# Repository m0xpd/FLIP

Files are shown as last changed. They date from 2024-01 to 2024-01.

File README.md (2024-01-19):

# FLIP

This repository describes a 'Bernoulli Gate', intended for switching applications in electronic music.

<p align='center'>
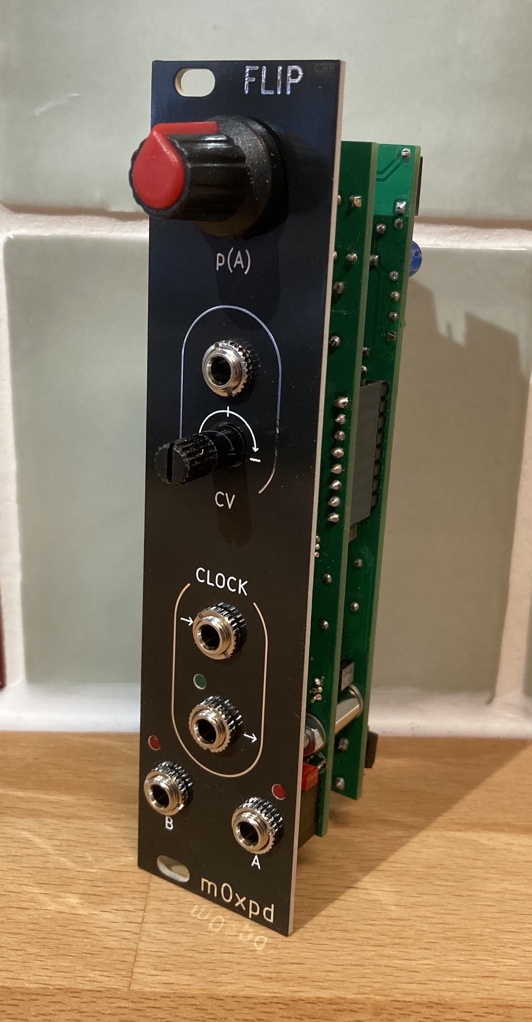
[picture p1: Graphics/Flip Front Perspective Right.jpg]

</p>
  
You can dive straight in to details of the [Eurorack module](https://github.com/m0xpd/Flip/blob/main/Eurorack/README.md), or a [stripboard layout for the circuit](https://github.com/m0xpd/FLIP/tree/main/Stripboard), or read more about the background and operation of this new design, below.

# Background

A Bernoulli Gate, named for Swiss mathematician and physicist [Daniel Bernoulli](https://en.wikipedia.org/wiki/Daniel_Bernoulli), takes a clock or gate input and routes it to one of two outputs, A & B, based on the 
value of an internally generated [Bernoulli Variable](https://web.stanford.edu/class/archive/cs/cs109/cs109.1178/lectureHandouts/070-bernoulli-binomial.pdf). When this (discrete, Boolean) random variable has value 1 the clock is routed to output A, and when the variable has value 0 the clock is routed to output B. The probability of the Bernoulli variable assuming value "1", p, is set by a front panel control (and/or by CV input). The probability of the variable assuming value "0" is (of course) 1-p. 

When the probability is set to p = 0.5, the process is equivalent to a "coin toss"; the input is routed to output A or B based on the outcome of a fair coin toss at each input onset. As p moves from the 0.5 value, the coin becomes increasingly "biased", with the outcome favouring one or other output. Larger values of p favors output A.

Bernoulli Gates have become familiar objects in modular synthesizers, the definitive example being Mutable Instruments' [Branches](https://pichenettes.github.io/mutable-instruments-documentation/modules/branches/) and various clones from other manufacturers. There is also a Bernoulli Gate within Mutable Instruments' [Marbles](https://pichenettes.github.io/mutable-instruments-documentation/modules/marbles/) module (and its clones), which is where it caught my interest. These implementations are achieved in software, running on microcontrollers.

# FLIP - a Hardware Bernoulli Gate

The Bernoulli Gate described in this repository is distinguished by being a completely **hardware realisation**. It generates the Bernoulli variable by a test of the instantaneous value of a linear ramp waveform. This ramp is running at a frequency several orders of magnitude above the clock frequencies typically used in synthesiser timing applications and is asynchronous to such input clocks/gates. Further, the ramp waveform is frequency-modulated by a second asynchronous signal, such that there is no possibility of 'phase' lock between an input clock and a subharmonic of the ramp waveform; the process is sufficiently random.

I should make it clear - I have absolutely nothing against the use of microcontrollers and DSP in modular synths, as I believe my work demonstrates. I designed FLIP for pleasure as a deliberate 'break' from playing with software-based systems in the recent development of my [STRACHEY](https://github.com/m0xpd/STRACHEY) sequencer. I based FLIP in hardware (rather than software) because I wanted the pleasure of something different. 

However, I should also confess to a feeling that we have become too ready to turn to soft solutions. There is something wasteful about having a little microcontroller (like Branches' ATMega88) sitting there doing something as simple as implementing (in that case two) Bernoulli Gates, even though it was *definitively the correct solution* for Mutable's commercial product. But I'm not designing for production - I'm enjoying myself, playing with ideas and materials I find to hand (often literally from the junk box). So - whilst I could easily have implemented my new Bernoulli Gate on an Atmel device or a PIC or similar, I think there remains something interesting and worthwhile in doing it 'old school'. 

I also recognise there are some members of the synth DIY community who actively do not like embedded/DSP. I repeat: **I'm NOT one of them**. But I'm pleased this project will be accessible to them.

Two versions of the hardware for FLIP are described in this repository. First, there is an implementation as a [Eurorack Module](https://github.com/m0xpd/Flip/blob/main/Eurorack/README.md), with full design details of the PCBs and front panel required for the 6HP module seen in the image at the head of this page. Second, I have included a [stripboard layout](https://github.com/m0xpd/Flip/blob/main/Stripboard/README.md) for the circuit for people who wish to build for a different format or who prefer to avoid the expense, delay, and minimum order quantities involved in making PCBs. The schematic for FLIP is presented as a single, system-level circuit in the [stripboard version](https://github.com/m0xpd/Flip/blob/main/Stripboard/README.md), whereas the [Eurorack version](https://github.com/m0xpd/Flip/blob/main/Eurorack/README.md) splits the system into two elements for implementation on two PCBs. Accordingly, those wishing to understand system operation might prefer to look at the schematic in the [stripboard folder](https://github.com/m0xpd/FLIP/tree/main/Stripboard) first. 

FLIP has two controls: the main 'probability' control and a control for the CV attenuverter. Advancing the probability control clockwise increases the probability that output A will be activated. When a positive CV is input, advancing the attenuverter control clockwise also increases the probability that A will 'fire' (the opposite sense applies when a negative CV is input). 

# Demo Video

A [short video](https://youtu.be/AdmhHrzYtKI), introduces FLIP and demonstrates its functions. The video is never going to win any oscars, not least as the camera is out of focus for the central 'demo' section. I don't know what changed between recording the music for the intro and 'closing credits' and the main, central demo portion. However, the message is clear, even if the image is not.    

# License

Material in this repository, including the circuit design and Eurorack implementation of FLIP, is published under a Creative Commons CC BY-SA 4.0 [License](https://github.com/m0xpd/Flip/blob/main/LICENSE.txt)

# Circuit Operation

Operation of the 'FLIP' Bernoulli Gate will now be described in some detail. Reference should be made to [this system-level schematic](https://github.com/m0xpd/Flip/blob/main/Stripboard/Graphics/m0xpd%20FLIP%20Bernoulli%20Gate.jpg) to which the component idents, circuit block names, and node names in the description below refer. [Note that these component idents differ from those used in the Eurorack version.]

FLIP derives a new value of a Bernoulli variable, p (as has been briefly introduced above) at the start of every clock input. This is done by comparing the instantaneous amplitude of a sawtooth wave to a threshold value. 

The sawtooth wave is generated by a 40106 oscillator (the block 'RAMP GENERATOR'), which is tuned (by adjustment of trimmer RV1, which should be set so there is approximately 1V on its wiper) to run at approximately 3.5kHz. The resulting sawtooth runs between voltages defined by the Schmitt trigger points of the 40106's inputs but the sawtooth is shifted to 0V mean by the high pass filter network C1,R3. Comparing this 'Saw' voltage with the fixed threshold voltage, 'Thres' (the magnitude of which is set either by the front panel probability potentiometer RV3 and/or by CV input to J2) produces a new Bernoulli variable, P at the output of the 'THRESHOLD COMPARATOR'. If the threshold is close to the bottom of the sawtooth's voltage range, the probability is close to (logical) one. If the threshold is close to the top of the sawtooth's voltage range, the probability is close to (logical) zero. the threshold voltage has been designed so it can be set slightly above or below the sawtooth's range, locking the probability to 1 or 0 (*and thereby setting the 'A' output on or off, with no switching action*), if required.

The photo below shows the 'Saw' waveform (in Yellow), the threshold voltage, 'Thres', set to just above the bottom of the sawtooth's voltage range (in Magenta) and the resulting Bernoulli variable, 'P' (in Cyan). The FM modulation of the saw oscillator (see below) has been disabled to make the image clearer and the results were captured from the prototype [stripboard](https://github.com/m0xpd/Flip/blob/main/Stripboard/README.md) system.

<p align='center'>
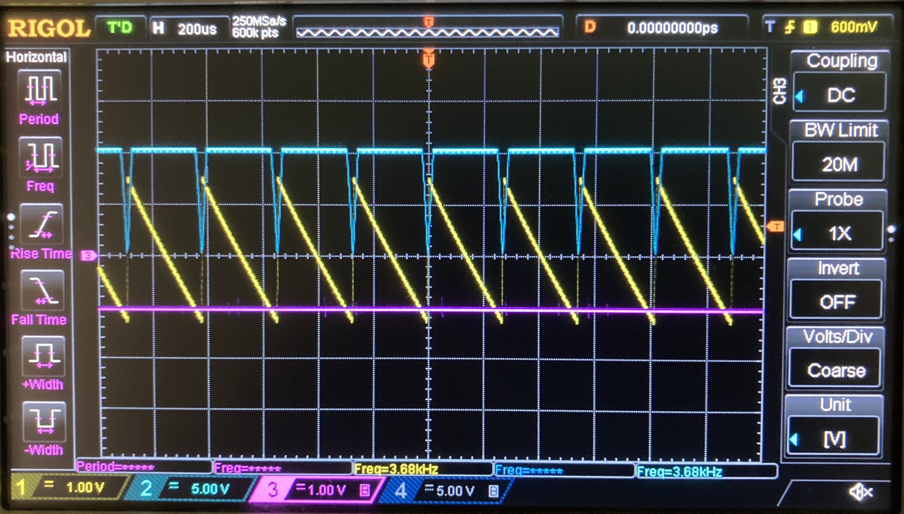
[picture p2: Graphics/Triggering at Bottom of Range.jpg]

</p>

It is seen that the Bernoulli variable is almost always "1", as expected.

In the practical circuit, frequency response and slew rate limitations in the op-amp used as the comparator constrain behaviour when the threshold is placed closer to the top of the sawtooth's range.

The photo below shows behaviour when the threshold, 'Thres' is at about 50% of the positive range of the sawtooth.

<p align='center'>
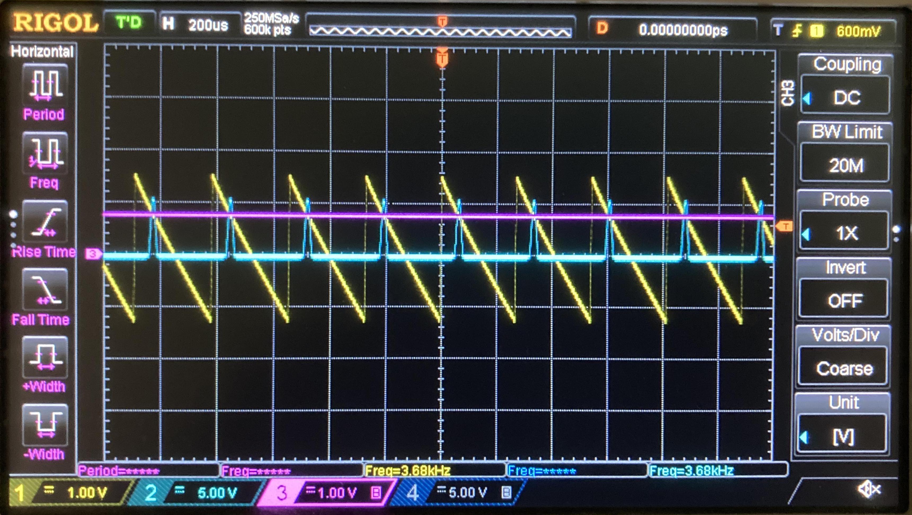
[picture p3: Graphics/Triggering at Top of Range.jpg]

</p>

It is seen that the Bernoulli variable is almost always "0"; this is the highest we can take the threshold voltage before it locks the gate "off". Taking the threshold value any higher in the practical circuit causes the comparator to fail to produce any 'non-zero' (in a logical sense) output. This is why the sawtooth wave - and the operation of FLIP - has been limited to 3.5kHz. 

The potential divider at the CV input, J2 (R13,R14) is loaded by the input resistance of the susbsequent attenuverter stage; this "loaded attenuator" produces around 6dB of attenuation in any configuration of the attenuverter. This allows a 5V CV signal to control the system, switching the gate from fully "on" to fully "off", whilst a higher CV input can achieve the same control at a lower attenuverter setting. Obviously, more subtle changes in configuration can be achieved with smaller control voltages, or with lower attenuverter settings.  

The external clock or gate signal is applied via J4 to FLIP's Schmitt trigger input circuit 'CLOCK IN' (with upward switchig threshold of 1.4V and downward threshold of 1.05V) to produce the gate signal, 'Input', which indicates an active input. The start of this input is detected by a typical passive differentiator / diode combination (C10,R30,D8), producing the signal 'dInput'.

The system is built around a trivial state machine which has two states, held on a SR flip-flop. I imlemented the flip-flop on 4001 (NOR) and 4081 (AND) gates, which were to hand (FLIP was designed around 'available materials') and provided sufficient logic resources for the remainder of the system. The transitions for the state machine were sufficient to define the Set and Reset signals:

The flip-flop is 'Set' when there is a leading edge of the clock AND the Bernoulli variable is 1 (Set = P.dInput).

The flip-flop is 'Reset' when 'Input' is false (Reset = _Input).

This system was found to work perfectly well in practical musical application, but offended me, as I understood there was possibility for a 'lock' between  a harmonic of the clock and the sawtooth wave, making the process less than random. I had anticipated this in design and arranged for the sawtooth oscillator to be voltage controlled. A second stage of the 40106 ('FM Osc') is used to implement an oscillator from which a triangular wave (at around 800Hz) is generated. This triangular voltage is used to frequency modulate the sawtooth, effectively removing the possibility of any 'lock' between the sawtooth and a periodic input signal. 

The photo below shows triggering with FM enabled:

<p align='center'>
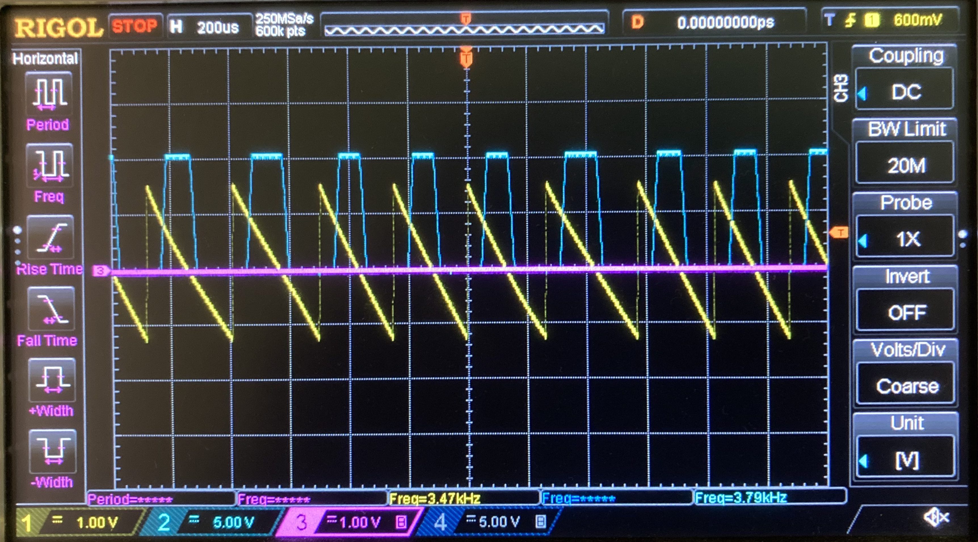
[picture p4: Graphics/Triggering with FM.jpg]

</p>

In this case, the threshold has been set to approximately 0V and the Bernoulli variable is returning a true value approximately 35% of the time (but not achieving the 50% score of a "fair" system, as the 0V threshold is above the middle of the range determined by the two limiting cases shown in the previous two oscilloscope screen shots). Variation in the period of the sawtooth (and the resulting outputs from the comparator) caused by the frequency modulation is clearly visible.

FLIP's three outputs use a simple 'emitter follower' buffer scheme taught by Ken Stone. The 'A' output follows directly the 'Q' output of the flip-flop. The 'B' output must be derived from additional logic to AND the complemented flip-flop state _Q with the input clock/gate signal. Finally, an output is provided which mirrors the input. This output is driven by a further inversion of _Input, rather than by adding load to the output of the CLOCK IN circuit, which could impact the edge detection circuit.

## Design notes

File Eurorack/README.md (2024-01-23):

# The 'FLIP' Bernoulli Gate for Eurorack

The Eurorack version of FLIP is implemented as a 'sandwich' construction of two printed circuit boards:

<p align='center'>
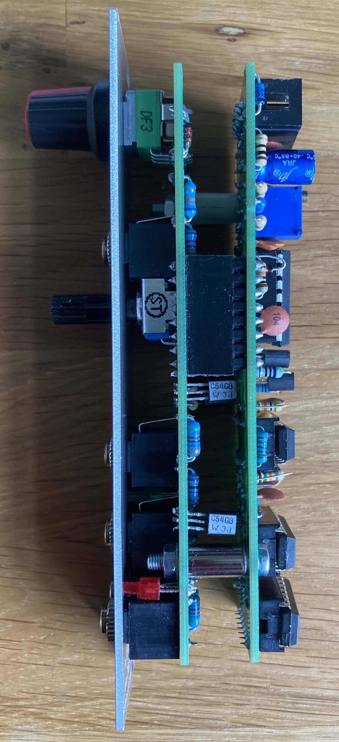
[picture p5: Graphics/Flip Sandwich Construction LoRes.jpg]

</p>

The [main board](https://github.com/m0xpd/FLIP/blob/main/Eurorack/Main%20Board/README.md) contains the majority of the active electronics, realised in 4000 series CMOS logic and a quad op-amp.

The [control board](https://github.com/m0xpd/FLIP/blob/main/Eurorack/Control%20Board/README.md) accommodates all the [front panel](https://github.com/m0xpd/FLIP/blob/main/Eurorack/Front%20Panel/README.md) components and the output buffer stages. 

The component board is mounted to the front panel by the probability control potentiometer, RV2, and five PJ398SM ('Thonkiconn') 3.5mm jack sockets.

The two PCBs are joined electrically by two 1*8 way 0.1 inch headers, with further mechanical security provided by a pair of 3mm bolts and spacers.

**Note:** the 12V line runs close to the upper spacer on the main board (on the bottom side of the PCB). If you use a metal spacer you would be well advised to insert an insulating washer at this point. I didn't have an insulating washer available on my first assembly, so I made an insulating spacer. This has now been replaced, as I got some M3 Nylon washers. Perhaps I'll move the 12V track if there's ever a revision of the PCB. 

Full design details of the [main board](https://github.com/m0xpd/FLIP/blob/main/Eurorack/Main%20Board/README.md), [control board](https://github.com/m0xpd/FLIP/blob/main/Eurorack/Control%20Board/README.md), and [front panel](https://github.com/m0xpd/FLIP/blob/main/Eurorack/Front%20Panel/README.md) are presented as KiCad projects. The folders also include schematics and BoMs, where relevant.

Populated boards from my first build are seen below.

First, there is an exploded view of the "outside" of the sandwich; the component side of the main board (left) and the bottom side of the control board (right), which houses the "user interface" components which protrude through the front panel:

<p align='center'>
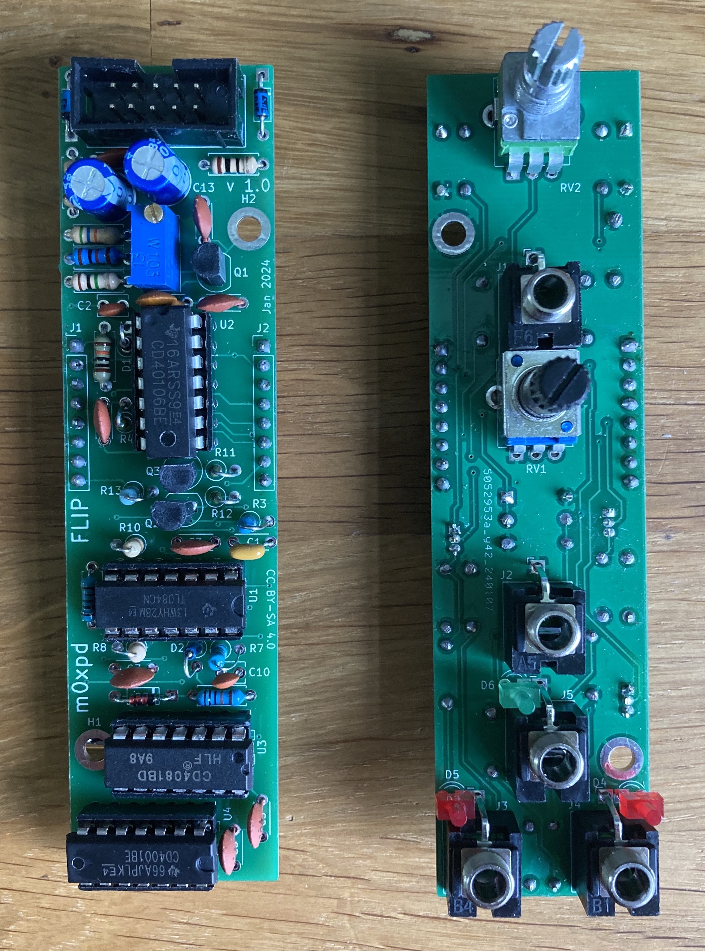
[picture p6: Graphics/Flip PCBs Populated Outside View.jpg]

</p>

Finally, an exploded view of the "inside" of the sandwich, showing the headers which join the boards, the bottom of the main board (left), and the component side of the control board (right):

<p align='center'>
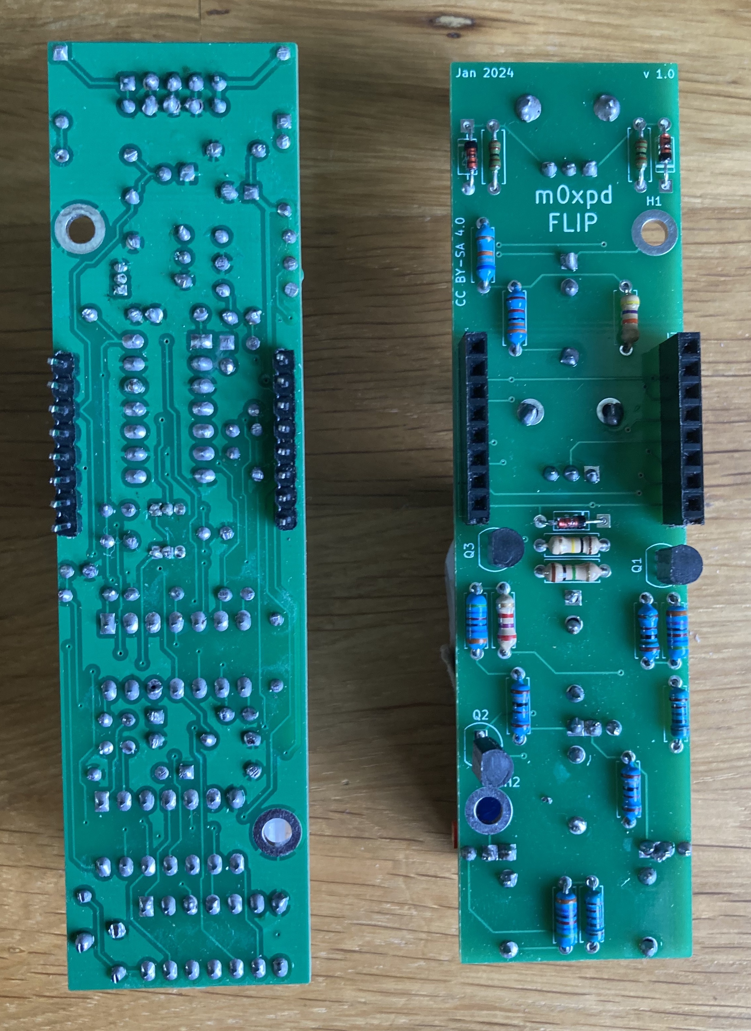
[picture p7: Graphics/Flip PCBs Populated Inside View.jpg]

</p>

(The two boards are exactly the same size but sit at slightly different distances from the camera in the images above, making them *appear* differently dimensioned.)

# Specifications

**Width:** 

FLIP is **6 HP wide**.

**Depth:**

FLIP extends **43 mm** behind the [front panel](https://github.com/m0xpd/FLIP/blob/main/Eurorack/Front%20Panel/README.md) when a conventional Eurorack power header **with strain relief** is inserted.

**Power Consumption:**

| Power Rail | Current |
|---|---|
| +12V | **5.5mA** (max) |
| -12V | **2.7mA** (max) |
| 5V | **0** |

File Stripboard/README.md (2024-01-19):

# A Stripboard Layout for the 'FLIP' Bernoulli Gate

During development I made a prototype on stripboard, based on a design made in [DIYLC](https://bancika.github.io/diy-layout-creator/) :

<p align='center'>
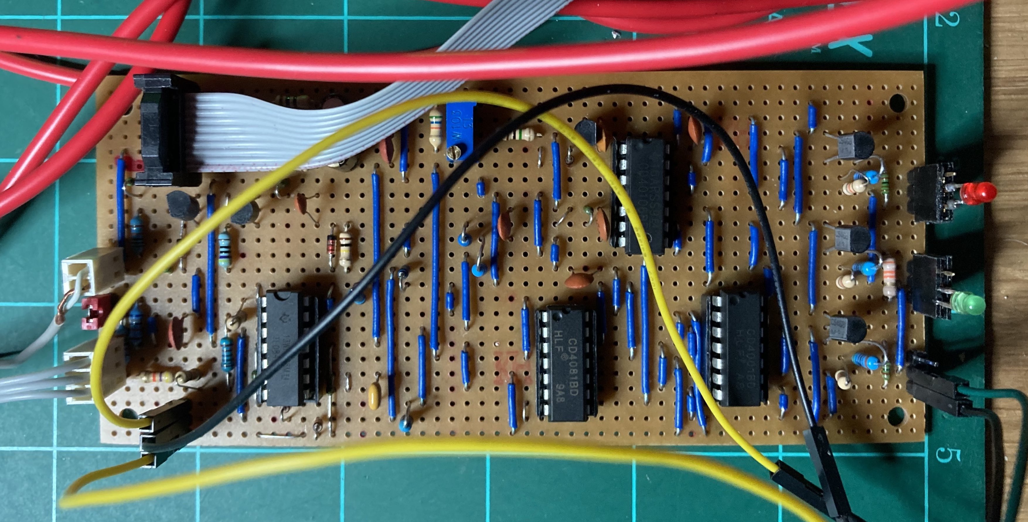
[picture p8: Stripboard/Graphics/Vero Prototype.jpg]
  
</p>

I have decided (for the first time) to publish a stripboard layout for this project as 
* it is small enough to make the stripboard layout manageable
* there is a considerable tradition within synth DIY for the use of stripboard - as demonstrated at [Eddy Bergman's site](https://www.eddybergman.com/)
* the test/development version was close enough to completion to make this task simple and, finally, 
* publishing a stripboard layout might make FLIP accessible to a few more potential users, who might otherwise be put off by the PCBs.

The stripboard layout will work well in "Kosmo" and MU applications etc (although the main board can easily be adapted for these formats too). There's more discussion of the implications of the stripboard layout's size [here](https://github.com/m0xpd/FLIP/blob/main/Stripboard/README.md#board-size-and-operation-on-different-power-rails)

# System Schematic

Before presenting the stripboard layout, we need to look at the schematic for the entire system (presented here as one sheet - unlike in the [Eurorack folder](https://github.com/m0xpd/FLIP/tree/main/Eurorack), where there are separate sheets for the two PCBs).

The schematic is linked below (click on the image to open the schematic at higher-resolution, which you can download):
<p align='center'>
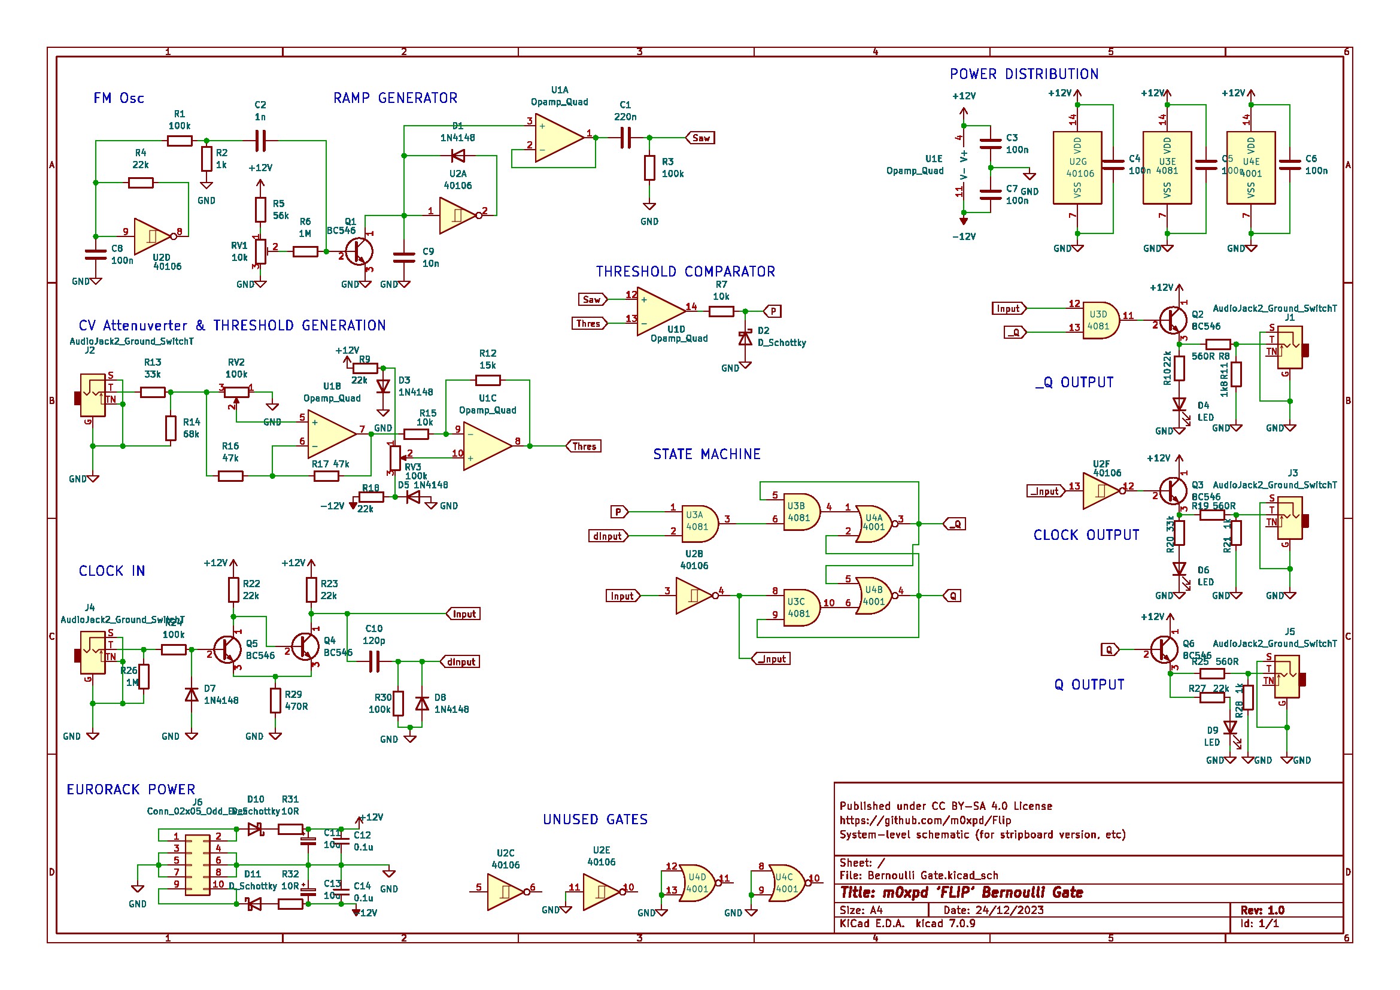
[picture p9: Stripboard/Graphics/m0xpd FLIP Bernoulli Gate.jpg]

</p>

There is a fairly detailed description of circuit operation, which references the schematic above, [here](https://github.com/m0xpd/Flip/tree/main#circuit-operation).

# Stripboard Layout

The prototype stripboard system seen pictured at the head of this page was made from a DIYLC design, which was found to have a few errors (this was my first time using the software). 

I corrected these errors on the prototype and on the layout, yielding the following design:

<p align='center'>
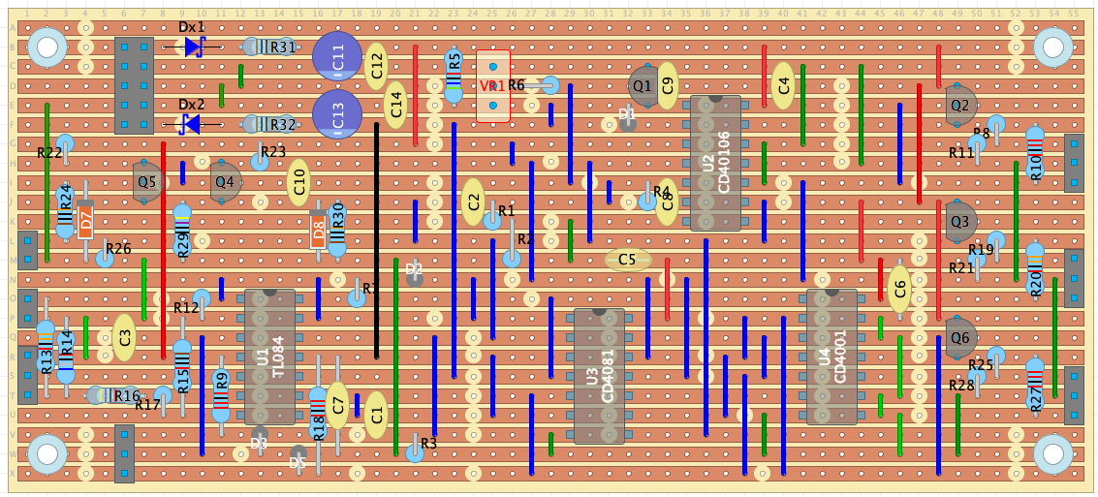
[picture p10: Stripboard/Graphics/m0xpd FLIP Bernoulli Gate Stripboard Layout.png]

</p>

In an attempt to make the layout clearer, +12V power links are shown in red, GROUND links are in green and -12V links are black. The remainder are blue.

The board is shown below (viewed from the **top/component side**) without components, to allow the cuts and links to be more clearly seen:

<p align='center'>
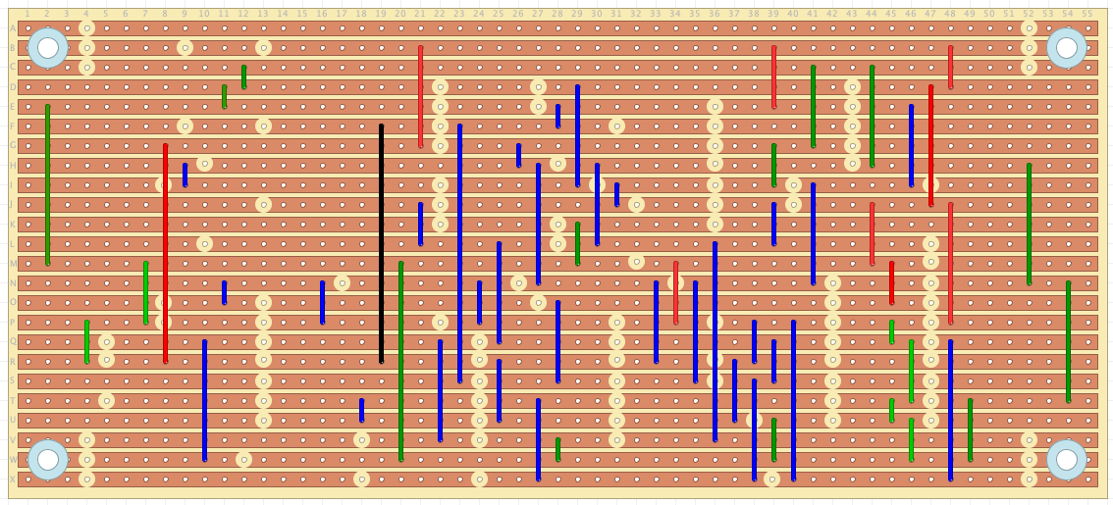
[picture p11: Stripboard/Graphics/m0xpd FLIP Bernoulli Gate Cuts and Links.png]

</p>

Finally, an image showing off-board connections is seen here:

<p align='center'>
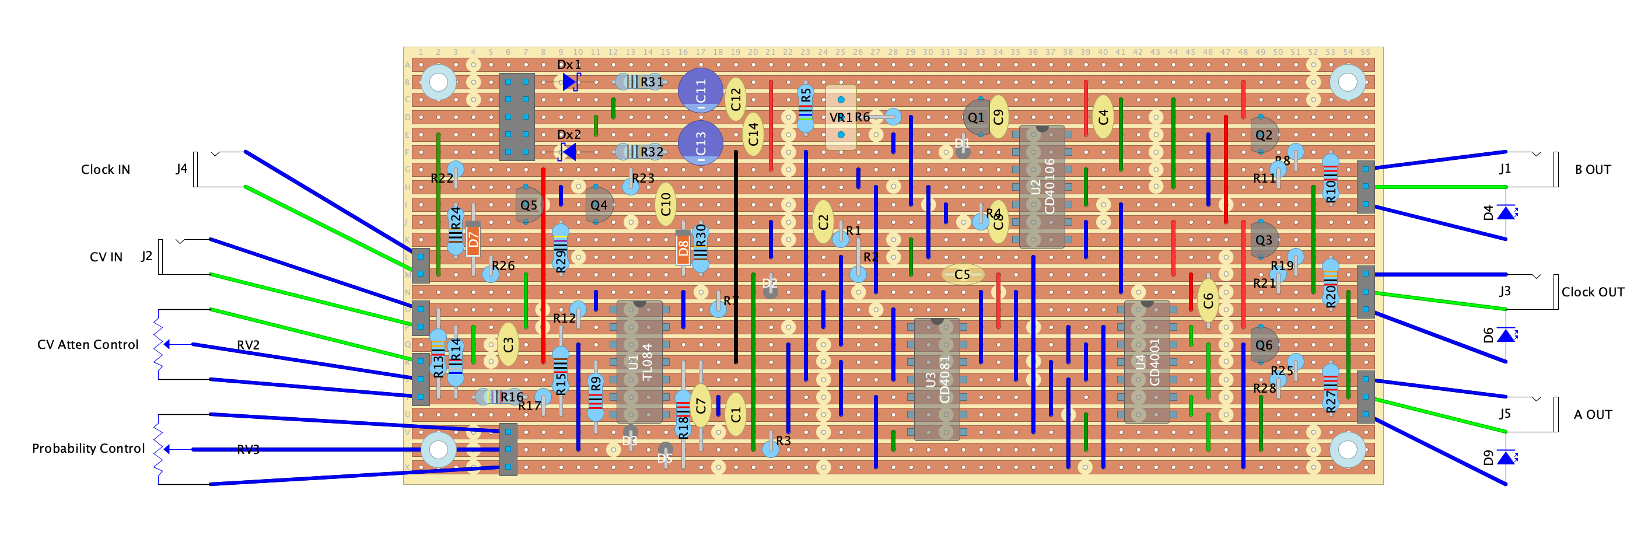
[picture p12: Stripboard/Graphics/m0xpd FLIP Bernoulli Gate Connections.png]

</p>

The entire DIYLC file is available for download [here](https://github.com/m0xpd/Flip/blob/main/Stripboard/Graphics/m0xpd%20FLIP%20Bernoulli%20Gate.diy). It must be opened in [DIYLC](https://bancika.github.io/diy-layout-creator/)

For those not familiar with github, the DIYLC file will open as a text file in a new window - you need to download the "Raw File", by clicking on the button at top right of the screen, as shown below:

<p align='center'>
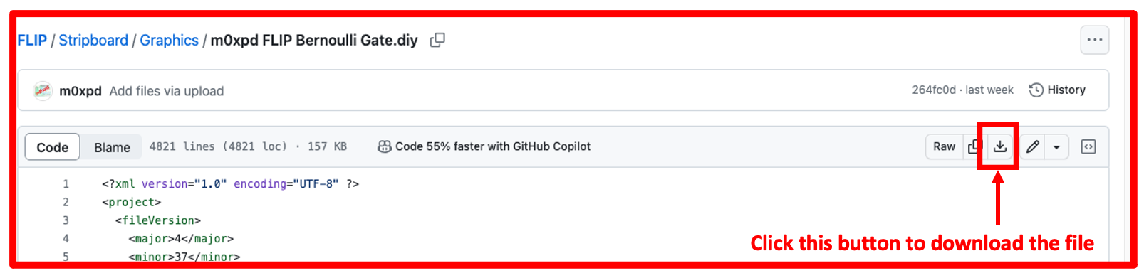
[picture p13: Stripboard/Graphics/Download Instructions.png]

</p>

# Important Warning - stripboard layout design not verified 

Whilst the layout above was developed directly from the prototype stripboard system, which is working, the layout **has not been verified**. 

It is offered in good faith and is - as far as I can see - an accurate mirror of my working stripboard system. However, I cannot claim it is yet verified.

I would appreciate either i) verification from anybody who builds from this layout or ii) notification of any errors/omissions. This repository will be updated, with appropriate citations, on receipt of such information.

# Board Size and Operation on Different Power Rails

The board used in this stripboard layout (55*24 holes, making the board approx. 140 * 65mm) was selected as the largest format used on [Eddy Bergman's site](https://www.eddybergman.com/) who, originally, was building for the [Kosmo standard](https://lookmumnocomputer.discourse.group/t/kosmo-specification/896). 

The stripboard FLIP layout is really too big for Eurorack (it certainly isn't skiff-friendly!) and would need a deep case to run in a Eurorack system. Most of my card frames are only 155mm deep, which isn't really enough to hold the stripboard. I have one (6U) frame which is about 175mm deep, but I don't plan to run the stripboard prototype *inside* my Eurorack system. I suggest anybody wishing to use FLIP in a Eurorack system should use the [dedicated Eurorack design](https://github.com/m0xpd/Flip/blob/main/Eurorack/README.md).

The stripboard layout shows a Eurorack power header and the system is designed for +/- 12V power operation. Other power connectors can easily fit in the space allocated for the 2*5 Eurorack header and it is self-evident how the power connections should be made. What is less clear is the potential for operation in contexts outside the Eurorack bipolar 12V power supply.

FLIP requires a bipolar power supply and (whilst I haven't tested it) I am confident that it will work on anything from +/- 9V to +/-15V, which will cover most synth standards. The only area I can see which *may* need some adjustment is the range over which the threshold voltage operates, (as this is set by diode forward voltage drops over D3,D5 and the setting of RV3), whilst the range of the sawtooth waveform will scale with the power supply (as the 40106's Schmitt trigger thresholds scale).

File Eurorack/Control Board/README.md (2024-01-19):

# FLIP Control Board

This folder contains details of the Control Board for the Eurorack implementation of the FLIP Bernoulli Gate.

There is a KiCad [Project file](https://github.com/m0xpd/FLIP/blob/main/Eurorack/Control%20Board/Files/Flip%20Control%20Board.kicad_pro) a [schematic file](https://github.com/m0xpd/FLIP/blob/main/Eurorack/Control%20Board/Files/Flip%20Control%20Board.kicad_sch) and a [PCB file](https://github.com/m0xpd/FLIP/blob/main/Eurorack/Control%20Board/Files/Flip%20Control%20Board.kicad_pcb). 

<p align='center'>
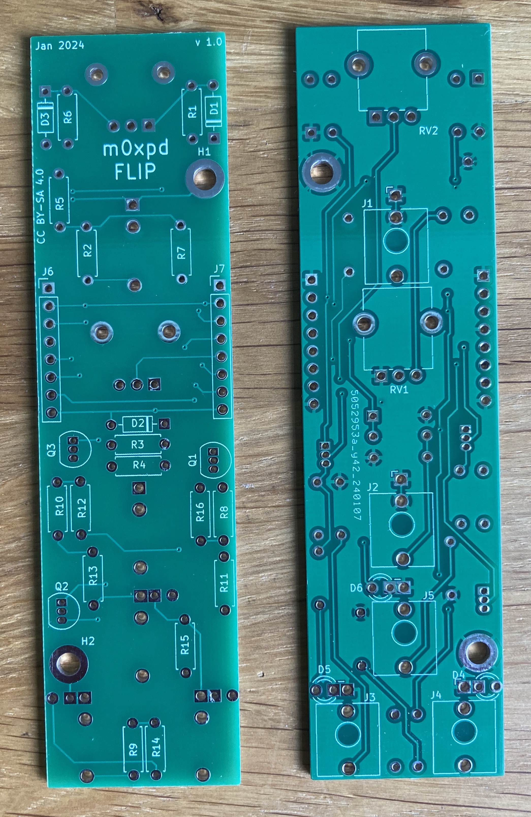
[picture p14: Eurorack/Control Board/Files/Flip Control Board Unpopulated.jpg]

</p>

[JLC](https://jlcpcb.com/) made my prototype PCBs (seen above) and did their usual great job.

There is also a schematic (click on the image below to open a larger version) and a BoM, saved as an [Excel file](https://github.com/m0xpd/FLIP/blob/main/Eurorack/Control%20Board/Files/Flip%20Control%20Board%20BoM.xlsx)

<p align='center'>
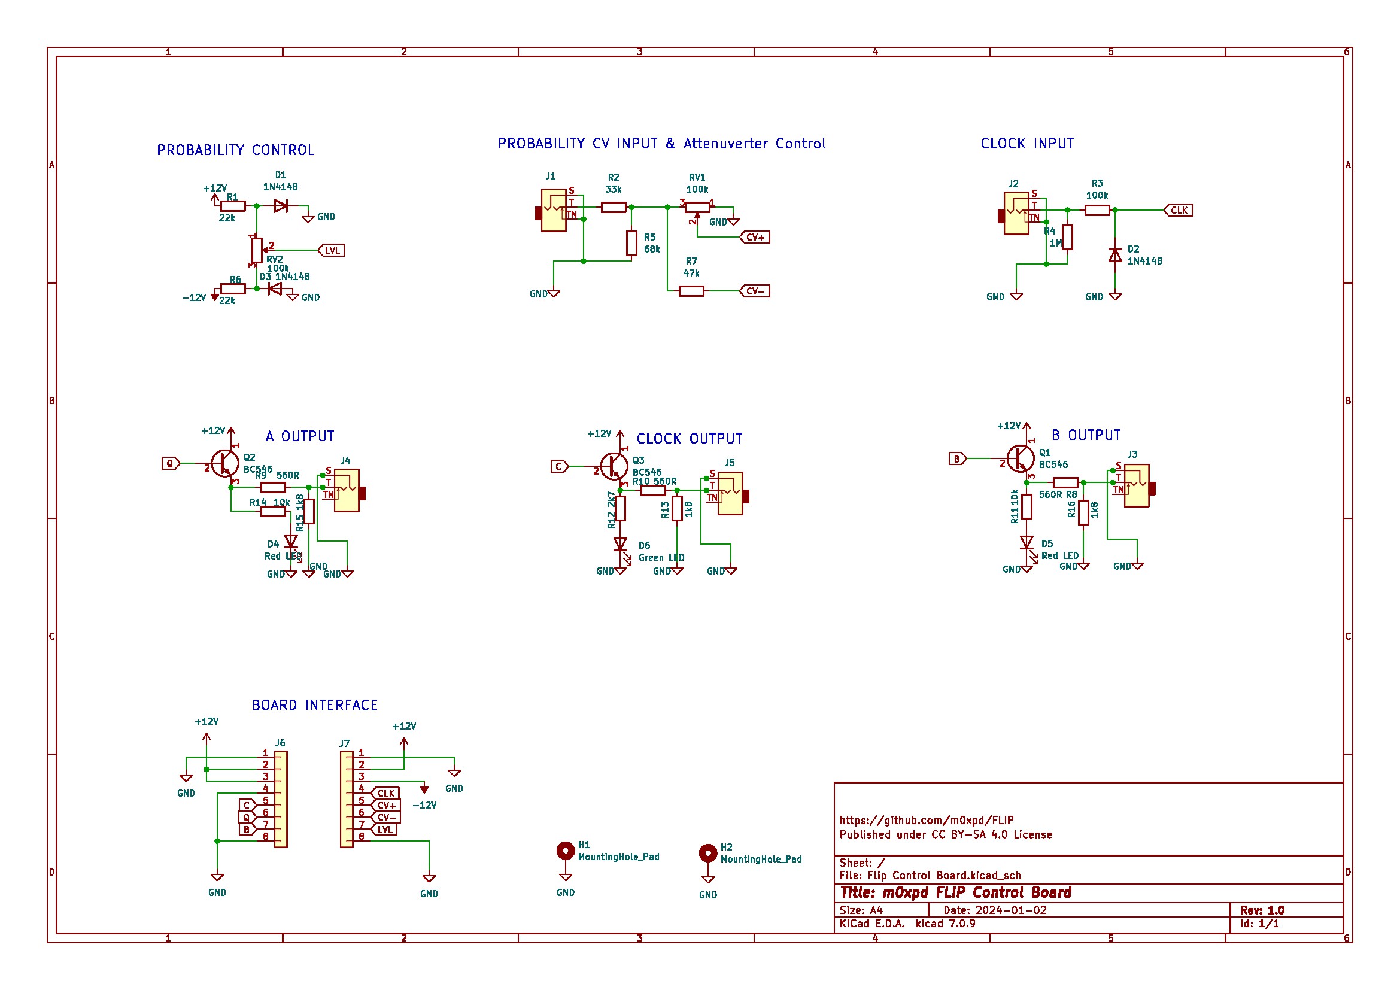
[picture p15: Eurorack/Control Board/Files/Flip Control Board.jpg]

</p>

The BoM specifies the PJ398SM ('Thonkiconn') Jacks, Alpha 9mm potentiometer and Song Huei trimmer, which are important for mechanical as well as electrical compatability.

As I've mentioned on the [Main Board page](https://github.com/m0xpd/FLIP/blob/main/Eurorack/Main%20Board/README.md), this is only the second project I've developed in KiCad and I'm still feeling my way around. The only aspect of the control board PCB which I regret is the (default, library) footprint for the transistors Q1:3, which has unnecessarily small and close pads. It works, but it asks a lot during soldering. I will modify this if a "v2" revision is ever made.

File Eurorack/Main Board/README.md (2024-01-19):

# FLIP Main Board

This [folder](https://github.com/m0xpd/FLIP/tree/main/Eurorack/Main%20Board) contains details of the Main Board for the Eurorack implementation of the FLIP Bernoulli Gate, expressed as a KiCad project.

There is a KiCad [Project file](https://github.com/m0xpd/FLIP/blob/main/Eurorack/Main%20Board/Files/Flip%20Main%20Board.kicad_pro) a [schematic file](https://github.com/m0xpd/FLIP/blob/main/Eurorack/Main%20Board/Files/Flip%20Main%20Board.kicad_sch) and a [PCB file](https://github.com/m0xpd/FLIP/blob/main/Eurorack/Main%20Board/Files/Flip%20Main%20Board.kicad_pcb). 

<p align='center'>
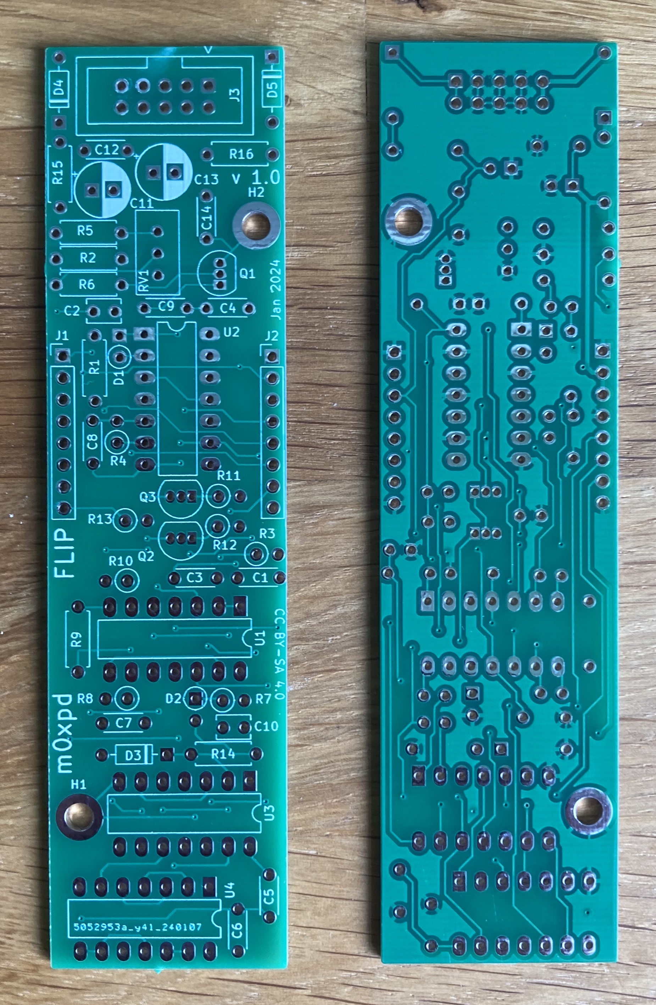
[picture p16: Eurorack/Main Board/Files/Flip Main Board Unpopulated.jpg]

</p>

[JLC](https://jlcpcb.com/) made my prototype PCBs (seen above) and did their usual great job.

There is also a schematic (click on the image below to open a larger version) and a BoM, saved as an [Excel file](https://github.com/m0xpd/FLIP/blob/main/Eurorack/Main%20Board/Files/Flip%20Main%20Board%20BoM.xlsx)

<p align='center'>
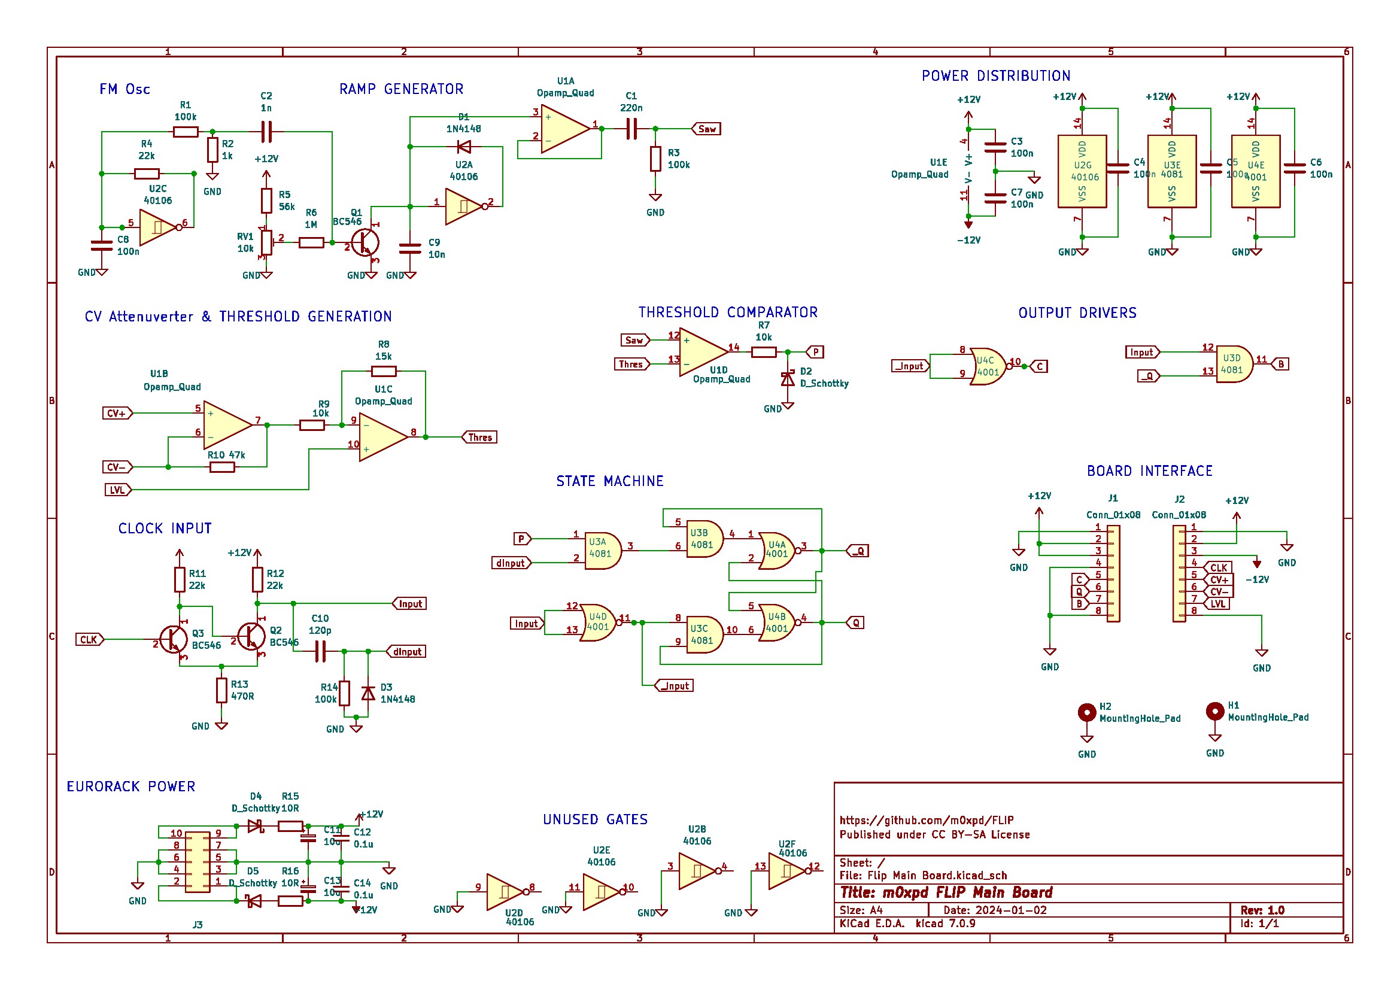
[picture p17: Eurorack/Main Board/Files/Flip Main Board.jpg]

</p>

The schematic above follows pretty closely the [system-level schematic presented in the stripboard folder](https://github.com/m0xpd/Flip/blob/main/Stripboard/Graphics/m0xpd%20FLIP%20Bernoulli%20Gate.jpg) apart from the fact that I have swapped the inverters (from the 40106) on the input to the Clock output stage and in the State Machine with unused gates in the 4001 package. This was done solely for convenience in laying out the PCB and has no impact on system operation - the Schmitt trigger inputs were not being exploited and the NOR gates can work perfectly well as inverters. Obviously, all the other 'missing' elements (user interface components, output buffers, etc) are on the [control board](https://github.com/m0xpd/FLIP/tree/main/Eurorack/Control%20Board).

This is only the second project I've developed in KiCad and I'm still feeling my way around. There are two issues on the main board PCB which could be better. The first is the (default, library) footprint for the transistors Q1:3, which has unnecessarily small and close pads. It works, but it asks a lot during the soldering phase! The second is proximity of the 12V line to mounting hole H2 on the bottom of the board; there isn't really enough safe clearance here for a full M3 washer. I managed this issue on my first build by using an insulated spacer between the main and control boards at this position; you could also use a single insulated washer. Whilst neither of these issues prevent use of the main board PCB as it stands, I will modify both if a "v2" revision of the main board PCB is ever made.

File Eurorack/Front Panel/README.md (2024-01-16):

# FLIP Front Panel

This [folder](https://github.com/m0xpd/FLIP/tree/main/Eurorack/Front%20Panel) contains a Eurorack front panel design for the FLIP Bernoulli Gate, expressed as a KiCad project.

There is a KiCad [Project file](https://github.com/m0xpd/FLIP/blob/main/Eurorack/Front%20Panel/Files/Flip%20Front%20Panel.kicad_pro) and a [PCB file](https://github.com/m0xpd/FLIP/blob/main/Eurorack/Front%20Panel/Files/Flip%20Front%20Panel.kicad_pcb). 

<p align='center'>
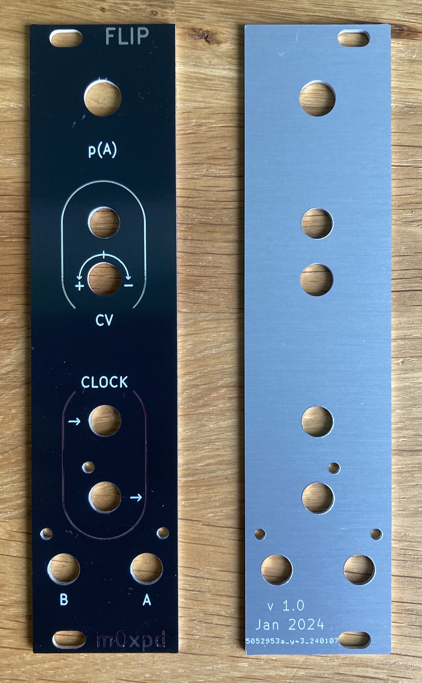
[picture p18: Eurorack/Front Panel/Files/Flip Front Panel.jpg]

</p>

[JLC](https://jlcpcb.com/) made my prototype panels (seen above) and did their usual great job. However, the black Aluminium panel with white lettering is now VERY expensive; if you want to save money, choose white with black lettering!

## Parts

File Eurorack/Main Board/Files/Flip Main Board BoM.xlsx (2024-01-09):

Source: | /Users/pauldarlington/Documents/Analog Synth/Bernoulli Gate/Flip Main Board/Flip Main Board.kicad_sch
Date: | Tuesday, January 09, 2024 at 03:11:41 PM
Tool: | Eeschema 7.0.9
Generator: | /Applications/KiCad/KiCad.app/Contents/SharedSupport/plugins/bom_csv_grouped_by_value.py
Component Count: | 48
Collated Components:
Item | Qty | Reference(s) | Value | Notes | LibPart | Footprint | Datasheet | DNP | Sim.Device | Sim.Pins
1 | 1 | C1 | 220n | All capacitors ceramic… | Device:C | Capacitor_THT:C_Disc_D4.3mm_W1.9mm_P5.00mm | ~
2 | 1 | C2 | 1n |  | Device:C | Capacitor_THT:C_Disc_D3.8mm_W2.6mm_P2.50mm | ~
3 | 6 | C3, C4, C5, C6, C7, C8 | 100n |  | Device:C | Capacitor_THT:C_Disc_D4.3mm_W1.9mm_P5.00mm | ~
4 | 1 | C9 | 10n |  | Device:C | Capacitor_THT:C_Disc_D4.3mm_W1.9mm_P5.00mm | ~
5 | 1 | C10 | 120p |  | Device:C | Capacitor_THT:C_Disc_D3.8mm_W2.6mm_P2.50mm | ~
6 | 2 | C11, C13 | 10u | except C11, C13: radial electrolytic | Device:C_Polarized_Small | Capacitor_THT:CP_Radial_D6.3mm_P2.50mm | ~
7 | 2 | C12, C14 | 0.1u |  | Device:C_Small | Capacitor_THT:C_Disc_D4.3mm_W1.9mm_P5.00mm | ~
8 | 1 | D1 | 1N4148 |  | Diode:1N4148 | Diode_THT:D_DO-35_SOD27_P2.54mm_Vertical_KathodeUp | https://assets.nexperia.com/documents/data-sheet/1N4148_1N4448.pdf |  | D | 1=K 2=A
9 | 1 | D2 | BAT42 |  | Device:D_Schottky | Diode_THT:D_DO-35_SOD27_P2.54mm_Vertical_AnodeUp | ~
10 | 1 | D3 | 1N4148 |  | Diode:1N4148 | Diode_THT:D_DO-35_SOD27_P7.62mm_Horizontal | https://assets.nexperia.com/documents/data-sheet/1N4148_1N4448.pdf |  | D | 1=K 2=A
11 | 2 | D4, D5 | 1N5157 |  | Device:D_Schottky | Diode_THT:D_DO-35_SOD27_P7.62mm_Horizontal | ~
12 | 2 | H1, H2 | MountingHole_Pad | M3 | Mechanical:MountingHole_Pad | MountingHole:MountingHole_3.2mm_M3_DIN965_Pad_TopBottom | ~
13 | 2 | J1, J2 | Conn_01x08 |  | Connector_Generic:Conn_01x08 | Connector_PinHeader_2.54mm:PinHeader_1x08_P2.54mm_Vertical | ~
14 | 1 | J3 | Conn_02x05_Odd_Even | Eurorack Power; Shrouded 2*5 2.54mm Plug | Connector_Generic:Conn_02x05_Odd_Even | Connector_IDC:IDC-Header_2x05_P2.54mm_Vertical | ~
15 | 3 | Q1, Q2, Q3 | BC546 | Substitute: BC547 etc or (with rotation) 2n3904 etc | Transistor_BJT:BC546 | Package_TO_SOT_THT:TO-92_Inline | https://www.onsemi.com/pub/Collateral/BC550-D.pdf
16 | 2 | R1, R14 | 100k |  | Device:R | Resistor_THT:R_Axial_DIN0207_L6.3mm_D2.5mm_P7.62mm_Horizontal | ~
17 | 1 | R2 | 1k |  | Device:R | Resistor_THT:R_Axial_DIN0207_L6.3mm_D2.5mm_P7.62mm_Horizontal | ~
18 | 1 | R3 | 100k |  | Device:R | Resistor_THT:R_Axial_DIN0207_L6.3mm_D2.5mm_P2.54mm_Vertical | ~
19 | 3 | R4, R11, R12 | 22k |  | Device:R | Resistor_THT:R_Axial_DIN0207_L6.3mm_D2.5mm_P2.54mm_Vertical | ~
20 | 1 | R5 | 56k |  | Device:R | Resistor_THT:R_Axial_DIN0207_L6.3mm_D2.5mm_P7.62mm_Horizontal | ~
21 | 1 | R6 | 1M |  | Device:R | Resistor_THT:R_Axial_DIN0207_L6.3mm_D2.5mm_P7.62mm_Horizontal | ~
22 | 1 | R7 | 10k |  | Device:R | Resistor_THT:R_Axial_DIN0207_L6.3mm_D2.5mm_P2.54mm_Vertical | ~
23 | 1 | R8 | 15k |  | Device:R | Resistor_THT:R_Axial_DIN0207_L6.3mm_D2.5mm_P2.54mm_Vertical | ~
24 | 1 | R9 | 10k |  | Device:R | Resistor_THT:R_Axial_DIN0207_L6.3mm_D2.5mm_P7.62mm_Horizontal | ~
25 | 1 | R10 | 47k |  | Device:R | Resistor_THT:R_Axial_DIN0207_L6.3mm_D2.5mm_P2.54mm_Vertical | ~
26 | 1 | R13 | 470R |  | Device:R | Resistor_THT:R_Axial_DIN0207_L6.3mm_D2.5mm_P2.54mm_Vertical | ~
27 | 2 | R15, R16 | 10R |  | Device:R | Resistor_THT:R_Axial_DIN0207_L6.3mm_D2.5mm_P7.62mm_Horizontal | ~
28 | 1 | RV1 | 10k | Multi-turn trimmer | Device:R_Potentiometer_Trim | Potentiometer_THT:Potentiometer_Bourns_3296W_Vertical | ~
29 | 1 | U1 | TL084 | Optional Substitute: TL074 | Device:Opamp_Quad | Package_DIP:DIP-14_W7.62mm_LongPads | ~
30 | 1 | U2 | 40106 |  | 4xxx:40106 | Package_DIP:DIP-14_W7.62mm_LongPads | https://assets.nexperia.com/documents/data-sheet/HEF40106B.pdf
31 | 1 | U3 | 4081 |  | 4xxx:4081 | Package_DIP:DIP-14_W7.62mm_LongPads | http://www.intersil.com/content/dam/Intersil/documents/cd40/cd4073bms-81bms-82bms.pdf
32 | 1 | U4 | 4001 |  | 4xxx:4001 | Package_DIP:DIP-14_W7.62mm_LongPads | http://www.intersil.com/content/dam/Intersil/documents/cd40/cd4000bms-01bms-02bms-25bms.pdf

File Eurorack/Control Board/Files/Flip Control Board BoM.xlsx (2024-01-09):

Source: | /Users/pauldarlington/Documents/Analog Synth/Bernoulli Gate/Flip Control Board/Flip Control Board.kicad_sch
Date: | Tuesday, January 09, 2024 at 09:57:17 AM
Tool: | Eeschema 7.0.9
Generator: | /Applications/KiCad/KiCad.app/Contents/SharedSupport/plugins/bom_csv_grouped_by_value.py
Component Count: | 36
Collated Components:
Item | Qty | Reference(s) | Value | Notes | Link / Suppliers | LibPart | Footprint | Datasheet | DNP | Sim.Device | Sim.Pins
1 | 3 | D1, D2, D3 | 1N4148 |  |  | Diode:1N4148 | Diode_THT:D_DO-35_SOD27_P7.62mm_Horizontal | https://assets.nexperia.com/documents/data-sheet/1N4148_1N4448.pdf |  | D | 1=K 2=A
2 | 2 | D4, D5 | Red LED | 2mm "Tower/Lighthouse" type | https://store.brightcomponents.co.uk/product-category/leds/tower-leds/ | Device:LED | LED_THT:LED_D3.0mm | ~
3 | 1 | D6 | Green LED | 2mm "Tower/Lighthouse" type | https://www.switchelectronics.co.uk/products/green-2mm-lighthouse-diffused-led | Device:LED | LED_THT:LED_D3.0mm | ~
4 | 2 | H1, H2 | MountingHole_Pad | Fit M3 bolts, nuts, spacers & washers |  | Mechanical:MountingHole_Pad | MountingHole:MountingHole_3.2mm_M3_DIN965_Pad_TopBottom | ~
5 | 5 | J1, J2, J3, J4, J5 | AudioJack2_SwitchT | Thonkiconn PJ398SM | https://www.thonk.co.uk/shop/thonkiconn/ | Connector_Audio:AudioJack2_SwitchT | Connector_Audio:Jack_3.5mm_QingPu_WQP-PJ398SM_Vertical_CircularHoles | ~
6 | 2 | J6, J7 | Conn_01x08 | Female |  | Connector_Generic:Conn_01x08 | Connector_PinHeader_2.54mm:PinHeader_1x08_P2.54mm_Vertical | ~
7 | 3 | Q1, Q2, Q3 | BC546 | Substitute BC547 or (with appropriate rotation) 2n3904, etc |  | Transistor_BJT:BC546 | Package_TO_SOT_THT:TO-92_Inline | https://www.onsemi.com/pub/Collateral/BC550-D.pdf
8 | 2 | R1, R6 | 22k |  |  | Device:R | Resistor_THT:R_Axial_DIN0207_L6.3mm_D2.5mm_P7.62mm_Horizontal | ~
9 | 1 | R2 | 33k |  |  | Device:R | Resistor_THT:R_Axial_DIN0207_L6.3mm_D2.5mm_P7.62mm_Horizontal | ~
10 | 2 | R11, R14 | 10k * | * Select for Red LED
11 | 1 | R12 | 2k7 * | * Select for Green LED
12 | 1 | R3 | 100k |  |  | Device:R | Resistor_THT:R_Axial_DIN0207_L6.3mm_D2.5mm_P7.62mm_Horizontal | ~
13 | 1 | R4 | 1M |  |  | Device:R | Resistor_THT:R_Axial_DIN0207_L6.3mm_D2.5mm_P7.62mm_Horizontal | ~
14 | 1 | R5 | 68k |  |  | Device:R | Resistor_THT:R_Axial_DIN0207_L6.3mm_D2.5mm_P7.62mm_Horizontal | ~
15 | 1 | R7 | 47k |  |  | Device:R | Resistor_THT:R_Axial_DIN0207_L6.3mm_D2.5mm_P7.62mm_Horizontal | ~
16 | 3 | R8, R9, R10 | 560R |  |  | Device:R | Resistor_THT:R_Axial_DIN0207_L6.3mm_D2.5mm_P7.62mm_Horizontal | ~
17 | 3 | R13, R15, R16 | 1k8 |  |  | Device:R | Resistor_THT:R_Axial_DIN0207_L6.3mm_D2.5mm_P7.62mm_Horizontal | ~
18 | 1 | RV1 | 100k (Linear) | Song Huei 9mm Trimmer | https://www.thonk.co.uk/shop/ttpots/ | Device:R_Potentiometer | Potentiometer_THT:Potentiometer_Alpha_RD901F-40-00D_Single_Vertical_CircularHoles | ~
19 | 1 | RV2 | 100k (Linear) | Alpha 9mm Pot | https://www.thonk.co.uk/shop/alpha-9mm-pots-vertical-t18/

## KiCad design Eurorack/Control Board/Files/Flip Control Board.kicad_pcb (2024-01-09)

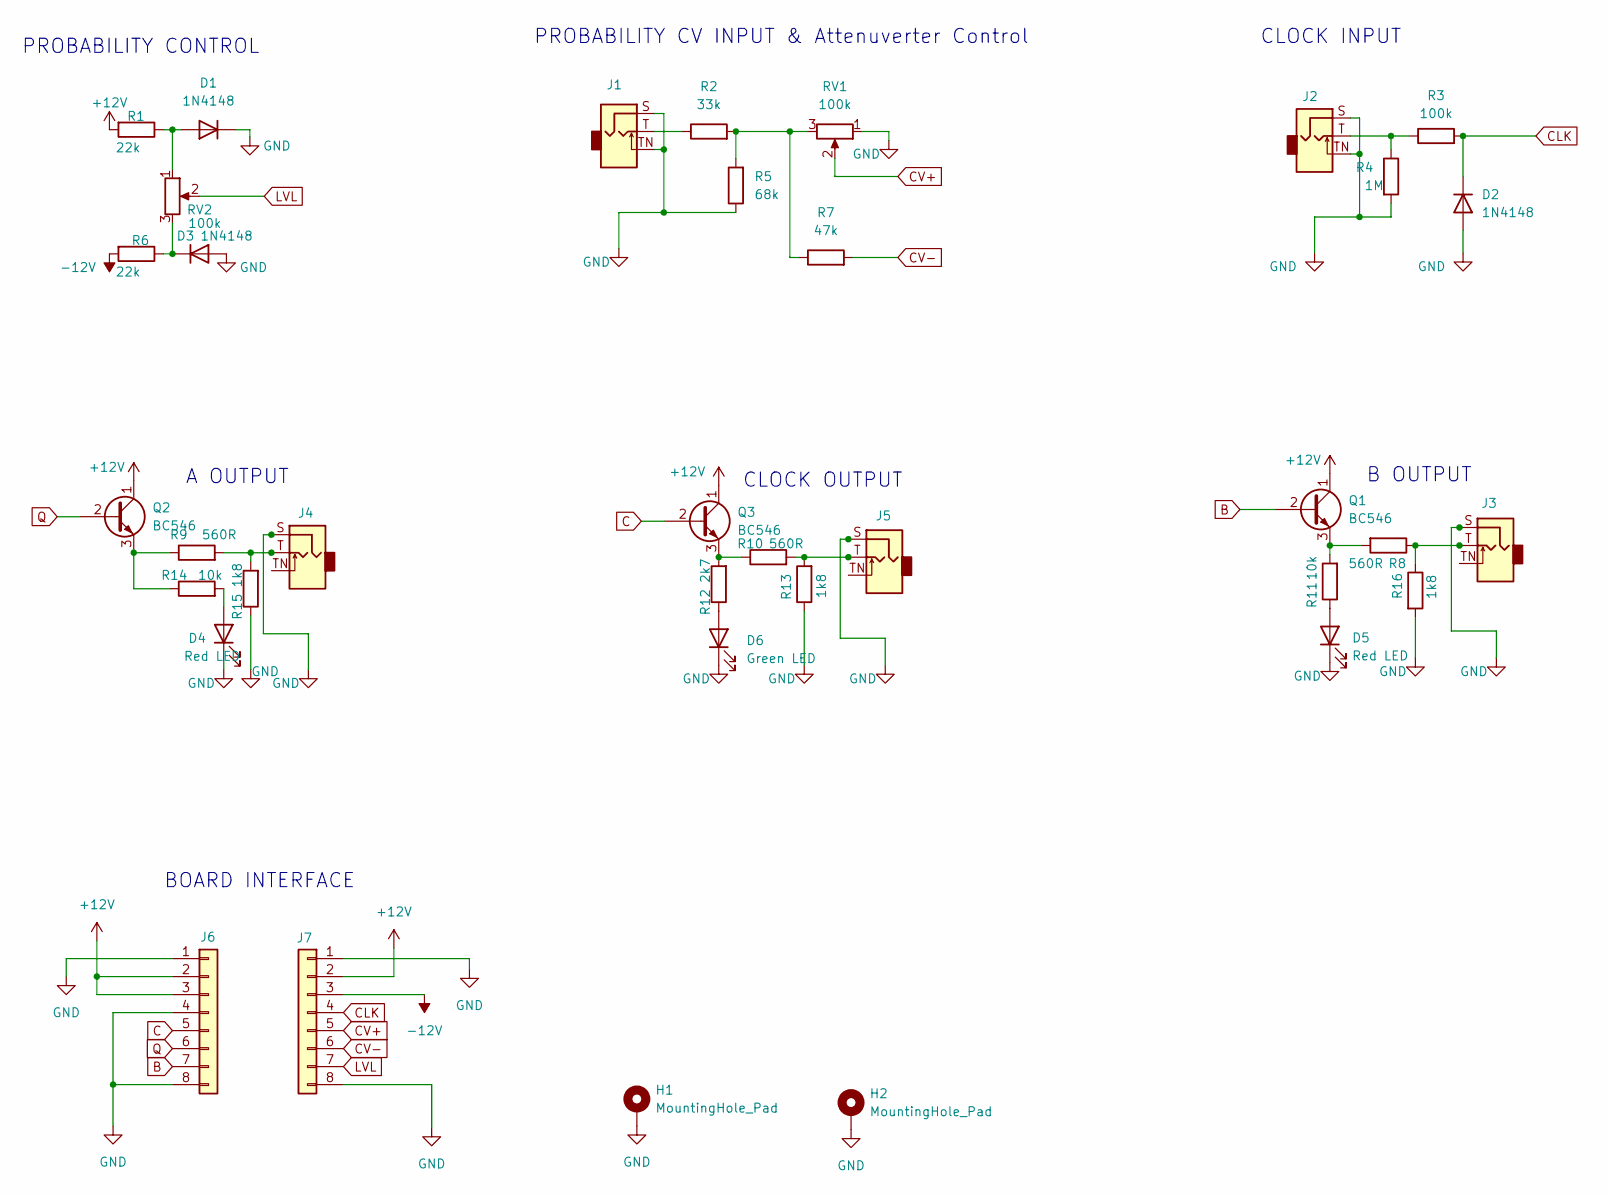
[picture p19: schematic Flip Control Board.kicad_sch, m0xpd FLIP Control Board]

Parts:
D1, D2, D3: 1N4148; D_DO-35_SOD27_P7.62mm_Horizontal
D4, D5: Red LED; LED_D3.0mm
D6: Green LED; LED_D3.0mm
H1, H2: MountingHole_Pad; MountingHole_3.2mm_M3_DIN965_Pad_TopBottom
J1, J2, J3, J4, J5: AudioJack2_SwitchT; Jack_3.5mm_QingPu_WQP-PJ398SM_Vertical_CircularHoles
J6, J7: Conn_01x08; PinHeader_1x08_P2.54mm_Vertical
Q1, Q2, Q3: BC546; TO-92_Inline
R1, R6: 22k; R_Axial_DIN0207_L6.3mm_D2.5mm_P7.62mm_Horizontal
R2: 33k; R_Axial_DIN0207_L6.3mm_D2.5mm_P7.62mm_Horizontal
R3: 100k; R_Axial_DIN0207_L6.3mm_D2.5mm_P7.62mm_Horizontal
R4: 1M; R_Axial_DIN0207_L6.3mm_D2.5mm_P7.62mm_Horizontal
R5: 68k; R_Axial_DIN0207_L6.3mm_D2.5mm_P7.62mm_Horizontal
R7: 47k; R_Axial_DIN0207_L6.3mm_D2.5mm_P7.62mm_Horizontal
R8, R9, R10: 560R; R_Axial_DIN0207_L6.3mm_D2.5mm_P7.62mm_Horizontal
R11, R14: 10k; R_Axial_DIN0207_L6.3mm_D2.5mm_P7.62mm_Horizontal
R12: 2k7; R_Axial_DIN0207_L6.3mm_D2.5mm_P7.62mm_Horizontal
R13, R15, R16: 1k8; R_Axial_DIN0207_L6.3mm_D2.5mm_P7.62mm_Horizontal
RV1, RV2: 100k; Potentiometer_Alpha_RD901F-40-00D_Single_Vertical_CircularH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

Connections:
+12V: J6.2, J6.3, J7.2, Q1.1 (C), Q2.1 (C), Q3.1 (C), R1.2
-12V: J7.3, R6.2
B: J6.7, Q1.2 (B)
C: J6.5, Q3.2 (B)
CLK: D2.1 (K), J7.4, R3.2
CV+: J7.5, RV1.2
CV-: J7.6, R7.2
GND: D1.1 (K), D2.2 (A), D3.2 (A), D4.1 (K), D5.1 (K), D6.1 (K), H1.1, H2.1, J1.S, J1.TN, J2.S, J2.TN, J3.S, J4.S, J5.S, J6.1, J6.4, J6.8, J7.1, J7.8, R4.2, R5.1, R13.1, R15.1, R16.2, RV1.1
LVL: J7.7, RV2.2
unnamed: D1.2 (A), R1.1, RV2.1
unnamed: D3.1 (K), R6.1, RV2.3
unnamed: D4.2 (A), R14.2
unnamed: D5.2 (A), R11.1
unnamed: D6.2 (A), R12.1
unnamed: J1.T, R2.1
unnamed: J2.T, R3.1, R4.1
unnamed: J3.T, R8.1, R16.1
unnamed: J4.T, R9.2, R15.2
unnamed: J5.T, R10.2, R13.2
unnamed: Q1.3 (E), R8.2, R11.2
unnamed: Q2.3 (E), R9.1, R14.1
unnamed: Q3.3 (E), R10.1, R12.2
unnamed: R2.2, R5.2, R7.1, RV1.3
Q: J6.6, Q2.2 (B)

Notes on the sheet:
B OUTPUT
A OUTPUT
CLOCK OUTPUT
PROBABILITY CONTROL
BOARD INTERFACE
CLOCK INPUT
PROBABILITY CV INPUT & Attenuverter Control

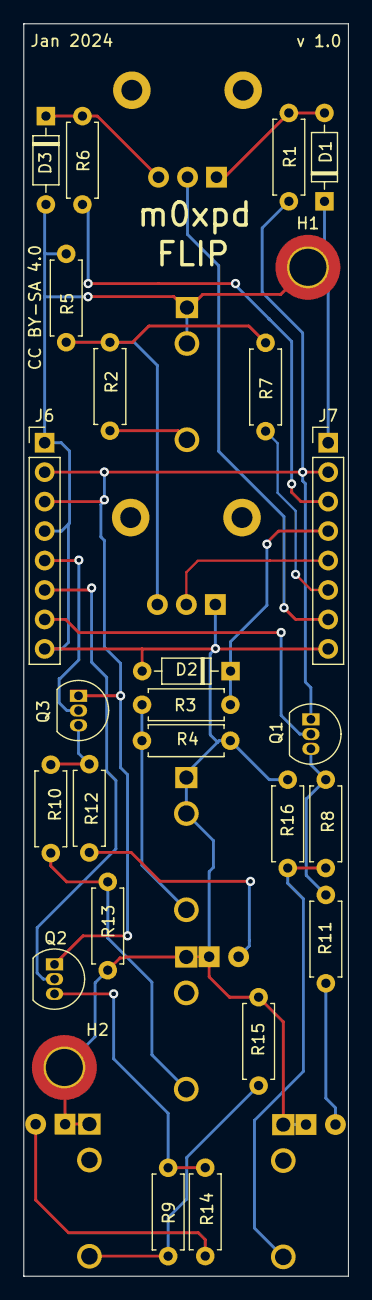
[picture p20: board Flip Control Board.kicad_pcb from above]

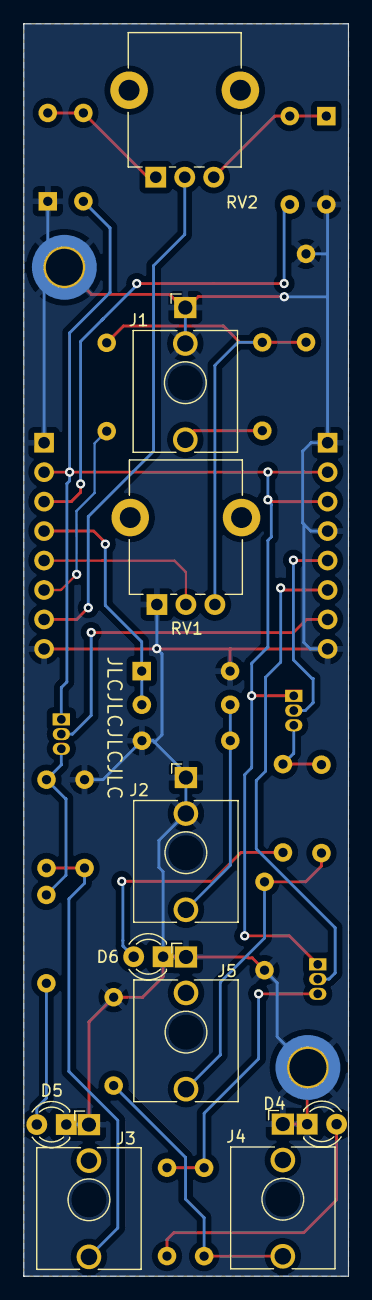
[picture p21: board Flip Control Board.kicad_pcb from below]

Board: 2 copper layers, 28.0 x 108.0 mm, 36 parts (10 on the bottom side), 24 nets.

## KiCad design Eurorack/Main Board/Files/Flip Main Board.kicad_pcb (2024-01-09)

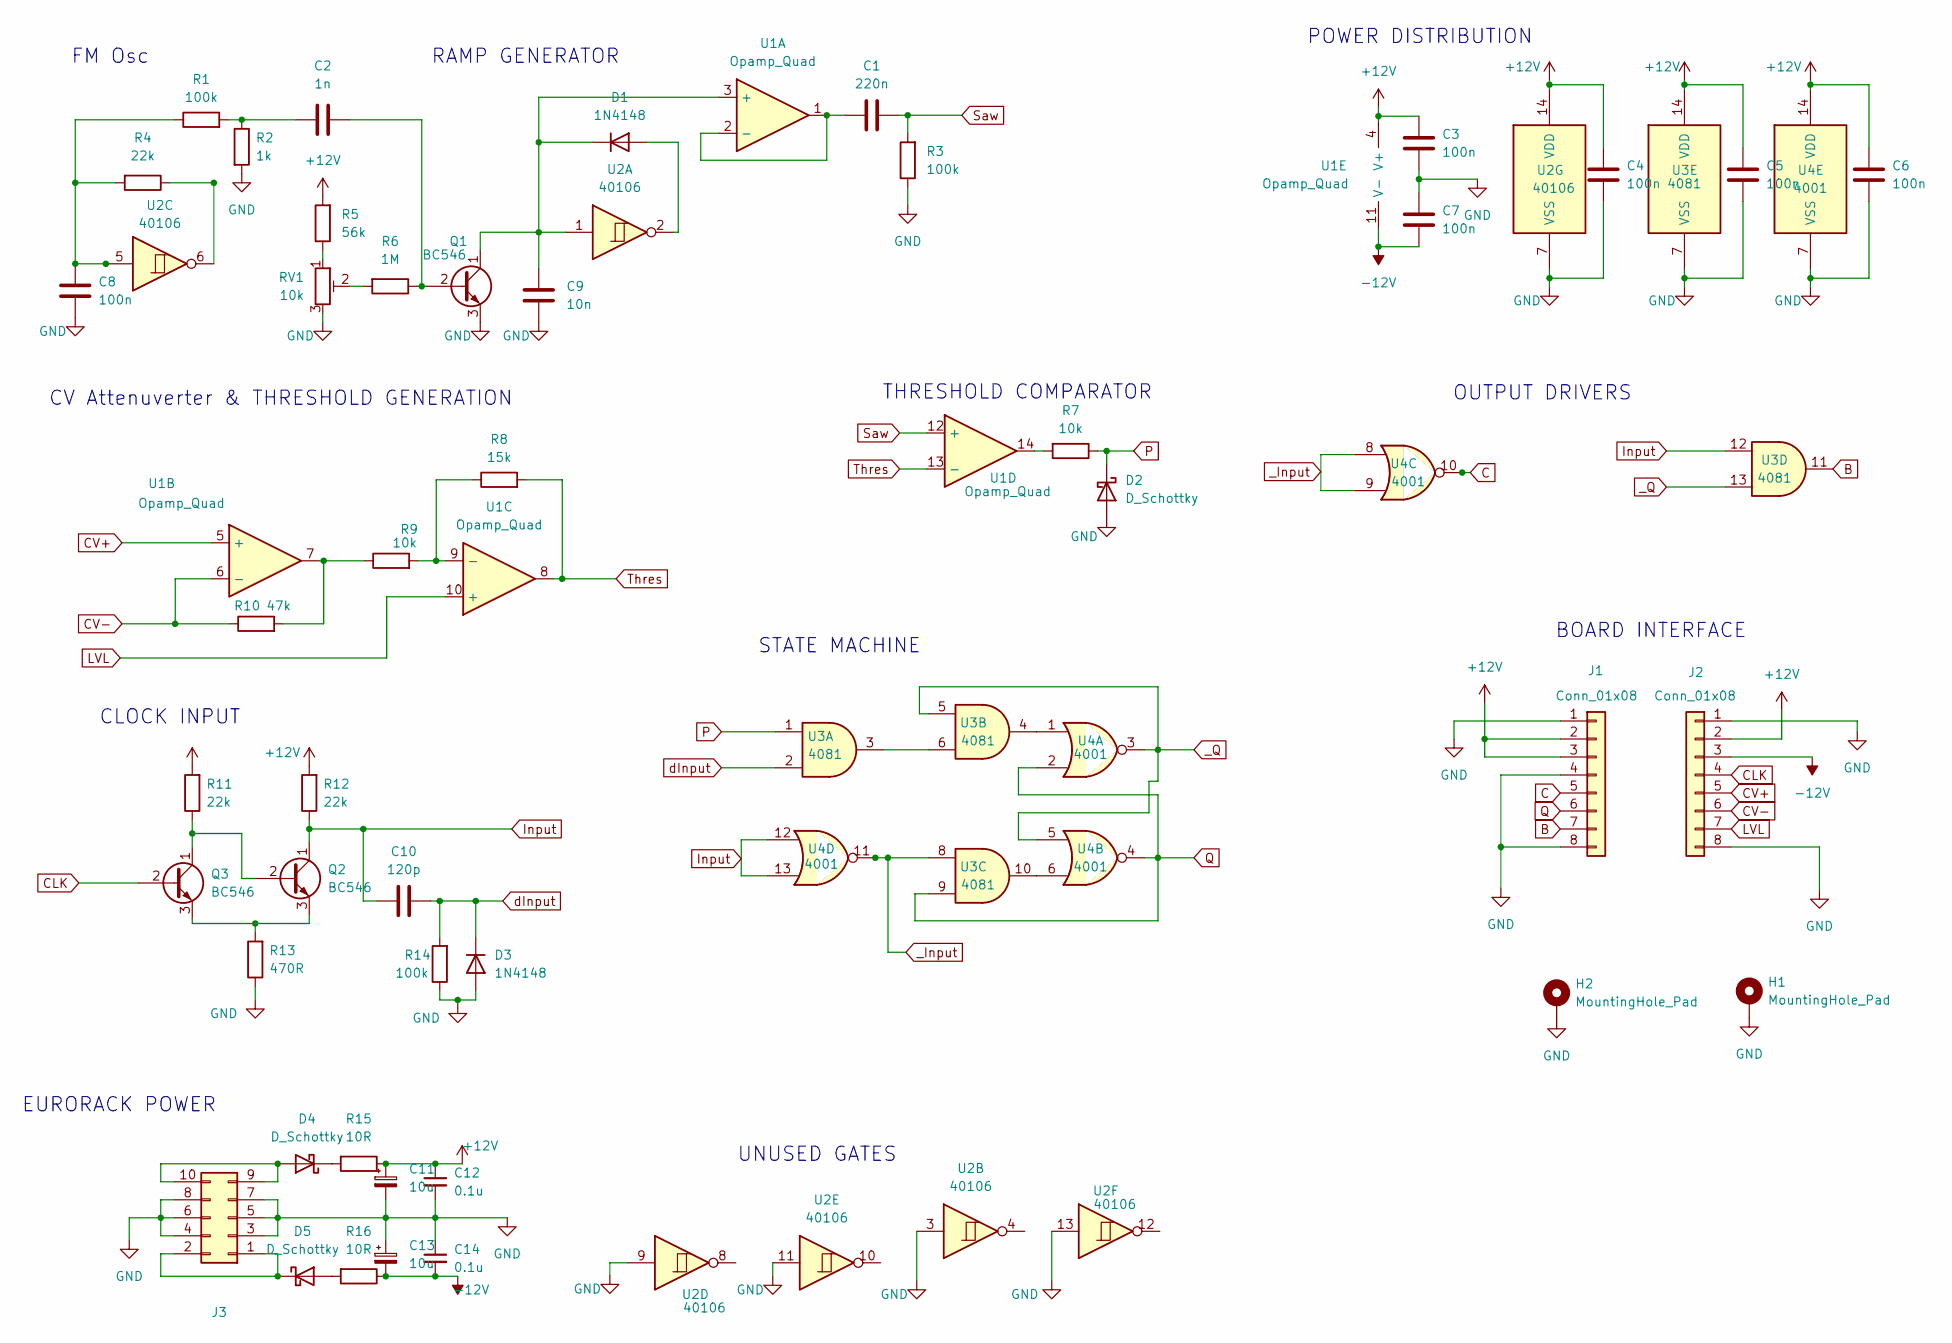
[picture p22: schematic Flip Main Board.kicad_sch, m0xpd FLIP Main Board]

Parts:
C1: 220n; C_Disc_D4.3mm_W1.9mm_P5.00mm
C2: 1n; C_Disc_D3.8mm_W2.6mm_P2.50mm
C3, C4, C5, C6, C7, C8: 100n; C_Disc_D4.3mm_W1.9mm_P5.00mm
C9: 10n; C_Disc_D4.3mm_W1.9mm_P5.00mm
C10: 120p; C_Disc_D3.8mm_W2.6mm_P2.50mm
C11, C13: 10u; CP_Radial_D6.3mm_P2.50mm
C12, C14: 0.1u; C_Disc_D4.3mm_W1.9mm_P5.00mm
D1: 1N4148; D_DO-35_SOD27_P2.54mm_Vertical_KathodeUp
D2: D_Schottky; D_DO-35_SOD27_P2.54mm_Vertical_AnodeUp
D3: 1N4148; D_DO-35_SOD27_P7.62mm_Horizontal
D4, D5: D_Schottky; D_DO-35_SOD27_P7.62mm_Horizontal
H1, H2: MountingHole_Pad; MountingHole_3.2mm_M3_DIN965_Pad_TopBottom
J1, J2: Conn_01x08; PinHeader_1x08_P2.54mm_Vertical
J3: Conn_02x05_Odd_Even; IDC-Header_2x05_P2.54mm_Vertical
Q1, Q2, Q3: BC546; TO-92_Inline
R1, R14: 100k; R_Axial_DIN0207_L6.3mm_D2.5mm_P7.62mm_Horizontal
R2: 1k; R_Axial_DIN0207_L6.3mm_D2.5mm_P7.62mm_Horizontal
R3: 100k; R_Axial_DIN0207_L6.3mm_D2.5mm_P2.54mm_Vertical
R4, R11, R12: 22k; R_Axial_DIN0207_L6.3mm_D2.5mm_P2.54mm_Vertical
R5: 56k; R_Axial_DIN0207_L6.3mm_D2.5mm_P7.62mm_Horizontal
R6: 1M; R_Axial_DIN0207_L6.3mm_D2.5mm_P7.62mm_Horizontal
R7: 10k; R_Axial_DIN0207_L6.3mm_D2.5mm_P2.54mm_Vertical
R8: 15k; R_Axial_DIN0207_L6.3mm_D2.5mm_P2.54mm_Vertical
R9: 10k; R_Axial_DIN0207_L6.3mm_D2.5mm_P7.62mm_Horizontal
R10: 47k; R_Axial_DIN0207_L6.3mm_D2.5mm_P2.54mm_Vertical
R13: 470R; R_Axial_DIN0207_L6.3mm_D2.5mm_P2.54mm_Vertical
R15, R16: 10R; R_Axial_DIN0207_L6.3mm_D2.5mm_P7.62mm_Horizontal
RV1: 10k; Potentiometer_Bourns_3296W_Vertical
U1: Opamp_Quad; DIP-14_W7.62mm_LongPads
U2: 40106; DIP-14_W7.62mm_LongPads
U3: 4081; DIP-14_W7.62mm_LongPads
U4: 4001; DIP-14_W7.62mm_LongPads

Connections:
+12V: C3.1, C4.1, C5.1, C6.1, C11.1, C12.1, J1.2, J1.3, J2.2, R5.2, R11.2, R12.2, R15.1, U1.4 (V+), U2.14 (VDD), U3.14 (VDD), U4.14 (VDD)
-12V: C7.2, C13.2, C14.2, J2.3, R16.1, U1.11 (V-)
B: J1.7, U3.11
C: J1.5, U4.10
CLK: J2.4, Q3.2 (B)
CV+: J2.5, U1.5 (+)
CV-: J2.6, R10.1, U1.6 (-)
GND: C3.2, C4.2, C5.2, C6.2, C7.1, C8.2, C9.2, C11.2, C12.2, C13.1, C14.1, D2.2 (A), D3.2 (A), H1.1, H2.1, J1.1, J1.4, J1.8, J2.1, J2.8, J3.3, J3.4, J3.5, J3.6, J3.7, J3.8, Q1.3 (E), R2.2, R3.1, R13.1, R14.1, RV1.3, U2.3, U2.7 (VSS), U2.9, U2.11, U2.13, U3.7 (VSS), U4.7 (VSS)
Input: C10.1, Q2.1 (C), R12.1, U3.12, U4.12, U4.13
LVL: J2.7, U1.10 (+)
unnamed: C2.1, R1.2, R2.1
unnamed: C8.1, R1.1, R4.2, U2.5
unnamed: D1.2 (A), U2.2
unnamed: C9.1, D1.1 (K), Q1.1 (C), U1.3 (+), U2.1
unnamed: D4.2 (A), J3.9, J3.10
unnamed: D4.1 (K), R15.2
unnamed: D5.2 (A), R16.2
unnamed: D5.1 (K), J3.1, J3.2
unnamed: C2.2, Q1.2 (B), R6.1
unnamed: Q2.2 (B), Q3.1 (C), R11.1
unnamed: Q2.3 (E), Q3.3 (E), R13.2
unnamed: R4.1, U2.6
unnamed: R5.1, RV1.1
unnamed: R6.2, RV1.2
unnamed: R7.2, U1.14
unnamed: R9.1, R10.2, U1.7
unnamed: C1.1, U1.1, U1.2 (-)
unnamed: R8.1, R9.2, U1.9 (-)
unnamed: U3.3, U3.6
unnamed: U3.4, U4.1
unnamed: U3.10, U4.6
P: D2.1 (K), R7.1, U3.1
Q: J1.6, U3.9, U4.2, U4.4
Saw: C1.2, R3.2, U1.12 (+)
Thres: R8.2, U1.8, U1.13 (-)
_Input: U3.8, U4.8, U4.9, U4.11
_Q: U3.5, U3.13, U4.3, U4.5
dInput: C10.2, D3.1 (K), R14.2, U3.2

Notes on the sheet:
CV Attenuverter & THRESHOLD GENERATION
EURORACK POWER
OUTPUT DRIVERS
STATE MACHINE
RAMP GENERATOR
BOARD INTERFACE
CLOCK INPUT
UNUSED GATES
THRESHOLD COMPARATOR
POWER DISTRIBUTION
FM Osc

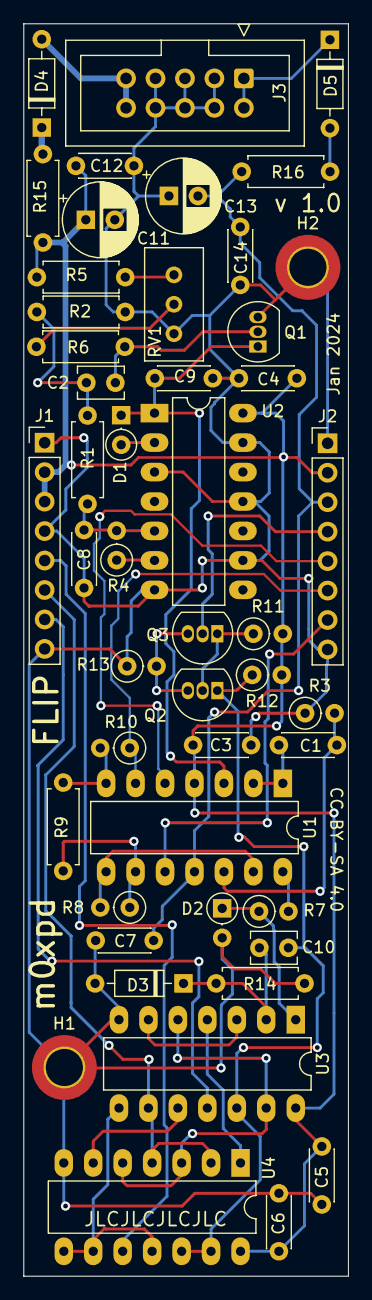
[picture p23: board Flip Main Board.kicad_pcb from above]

Board: 2 copper layers, 28.0 x 108.0 mm, 48 parts (0 on the bottom side), 38 nets.

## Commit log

2024-01-04 Rename Stripboard/Vero Prototype.jpg to Stripboard/Graphics/Vero Prototype.jpg
2024-01-09 Rename Eurorack/Main Board/Flip Main Board.jpg to Eurorack/Main Board/Files/Flip Main Board.jpg
2024-01-09 Rename Eurorack/Main Board/Flip Main Board.kicad_pcb to Eurorack/Main Board/Files/Flip Main Board.kicad_pcb
    [Flip Main Board.kicad_pcb]
2024-01-09 Rename Eurorack/Main Board/Flip Main Board.kicad_pro to Eurorack/Main Board/Files/Flip Main Board.kicad_pro
2024-01-09 Rename Eurorack/Main Board/Flip Main Board.kicad_sch to Eurorack/Main Board/Files/Flip Main Board.kicad_sch
    [Flip Main Board.kicad_sch]
2024-01-09 Rename Eurorack/Control Board/Flip Control Board BoM.xlsx to Eurorack/Control Board/Files/Flip Control Board BoM.xlsx
    [Flip Control Board BoM.xlsx]
2024-01-09 Rename Eurorack/Control Board/Flip Control Board.jpg to Eurorack/Control Board/Files/Flip Control Board.jpg
2024-01-09 Rename Eurorack/Control Board/Flip Control Board.kicad_pcb to Eurorack/Control Board/Files/Flip Control Board.kicad_pcb
    [Flip Control Board.kicad_pcb]
2024-01-09 Rename Eurorack/Control Board/Flip Control Board.kicad_pro to Eurorack/Control Board/Files/Flip Control Board.kicad_pro
2024-01-09 Rename Eurorack/Control Board/Flip Control Board.kicad_sch to Eurorack/Control Board/Files/Flip Control Board.kicad_sch
    [Flip Control Board.kicad_sch]
2024-01-09 Rename Eurorack/Front Panel/Flip Front Panel.kicad_pcb to Eurorack/Front Panel/Files/Flip Front Panel.kicad_pcb
    [Flip Front Panel.kicad_pcb]
2024-01-09 Rename Eurorack/Front Panel/Flip Front Panel.kicad_pro to Eurorack/Front Panel/Files/Flip Front Panel.kicad_pro
2024-01-09 Rename Eurorack/Front Panel/Flip Front Panel.kicad_sch to Eurorack/Front Panel/Files/Flip Front Panel.kicad_sch
    [Flip Front Panel.kicad_sch]
2024-01-09 Rename Eurorack/Main Board/Flip Main Board BoM.xlsx to Eurorack/Main Board/Files/Flip Main Board BoM.xlsx
    [Flip Main Board BoM.xlsx]

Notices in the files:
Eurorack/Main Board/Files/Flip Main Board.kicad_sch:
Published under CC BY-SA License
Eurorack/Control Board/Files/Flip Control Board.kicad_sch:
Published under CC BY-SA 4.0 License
